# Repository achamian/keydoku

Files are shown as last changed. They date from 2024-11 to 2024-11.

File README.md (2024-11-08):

# Keydoku

<p align="center">
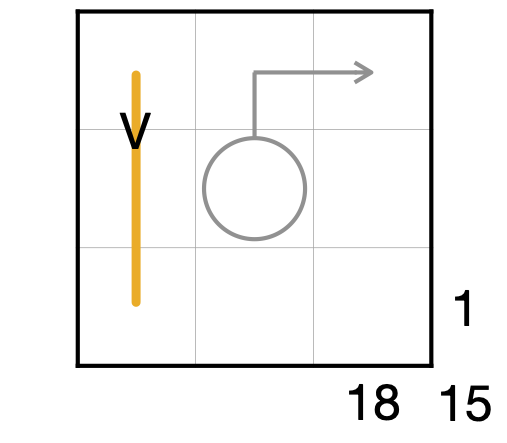
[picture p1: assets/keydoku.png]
  
</p>

## Rules

* Fill in the digits 1 to 9 in the grid.
* Set of three sequential cells along the orange line must contain a low digit (123), a middle digit (456) and a high digit (789).
* Digits on the orange line have same modulo 3.
* Digit in the circle is sum of the digits on the attached line.
* Digit outside the grid is either a Sky Scrapper clue or represnt sum of the digits on corrosponding row, column or diagonal.

# Keymap

<p align="center">
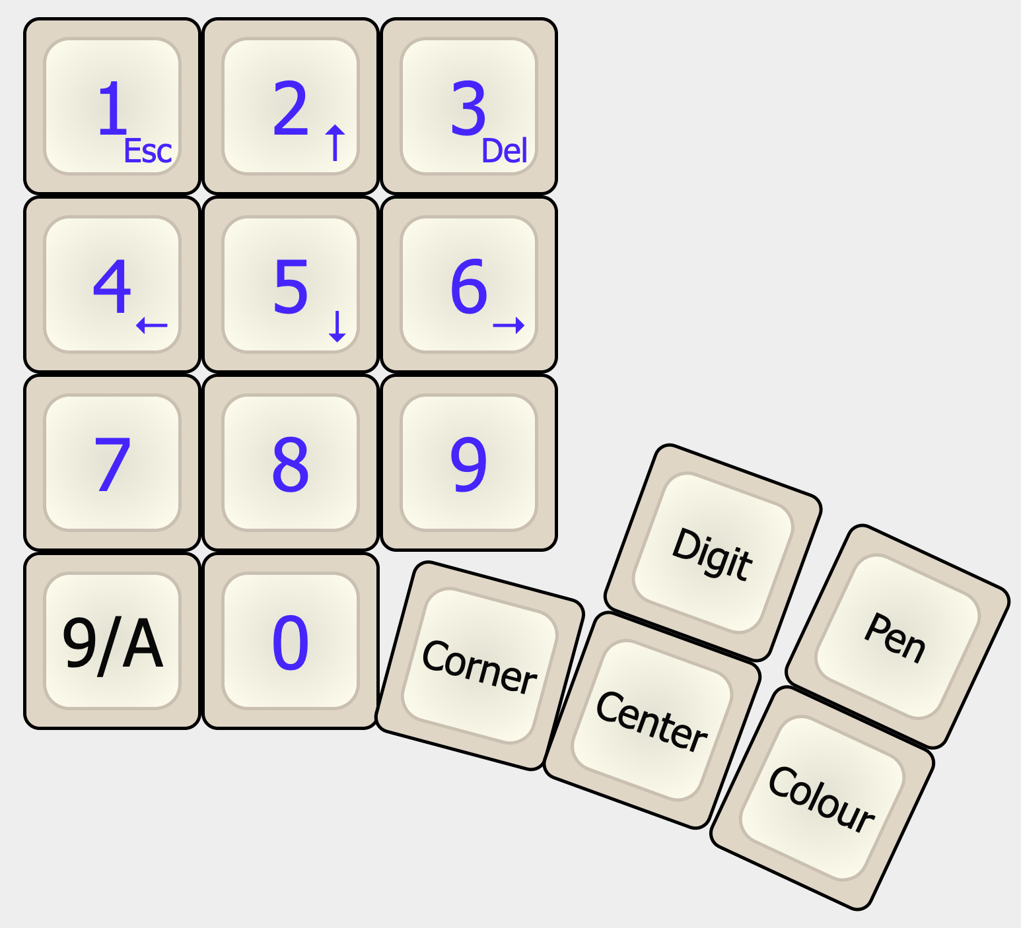
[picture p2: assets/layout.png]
  
</p>

### Things To Note

* Holding down the `Corner`, `Center` or `Colour` keys will switch to respective mode till the key is released.u
* Holding down `Digit` key will enable arrow keys, escape and delete.

### Update default keymap

Default keymap can be changed by visiting [Vial](https://vial.rocks/) while keyboard is connected.

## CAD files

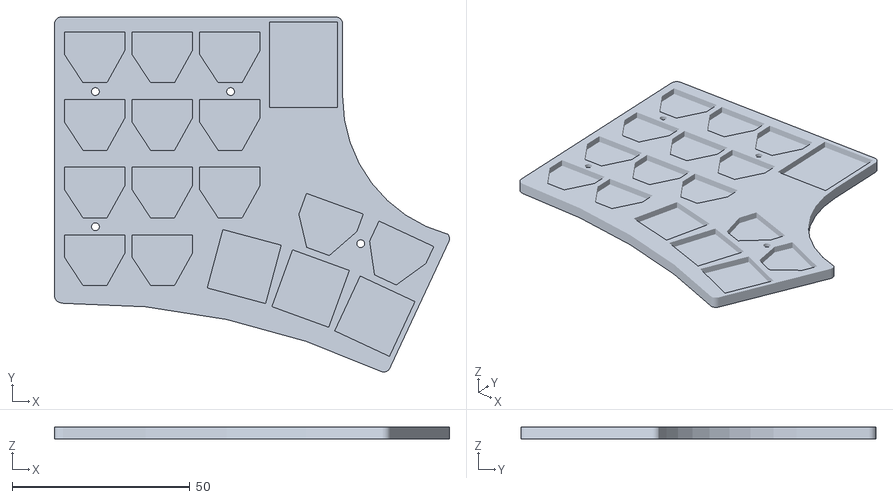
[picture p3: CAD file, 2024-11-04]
case/bottom_case.stl
111.0 x 99.9 x 3.50

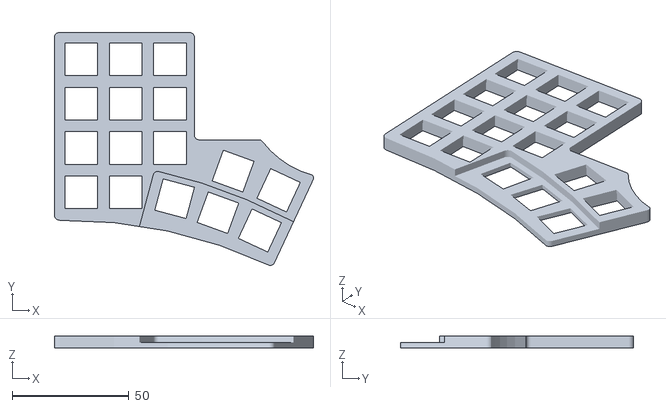
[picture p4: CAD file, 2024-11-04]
case/top_case.stl
111.0 x 99.9 x 5.10

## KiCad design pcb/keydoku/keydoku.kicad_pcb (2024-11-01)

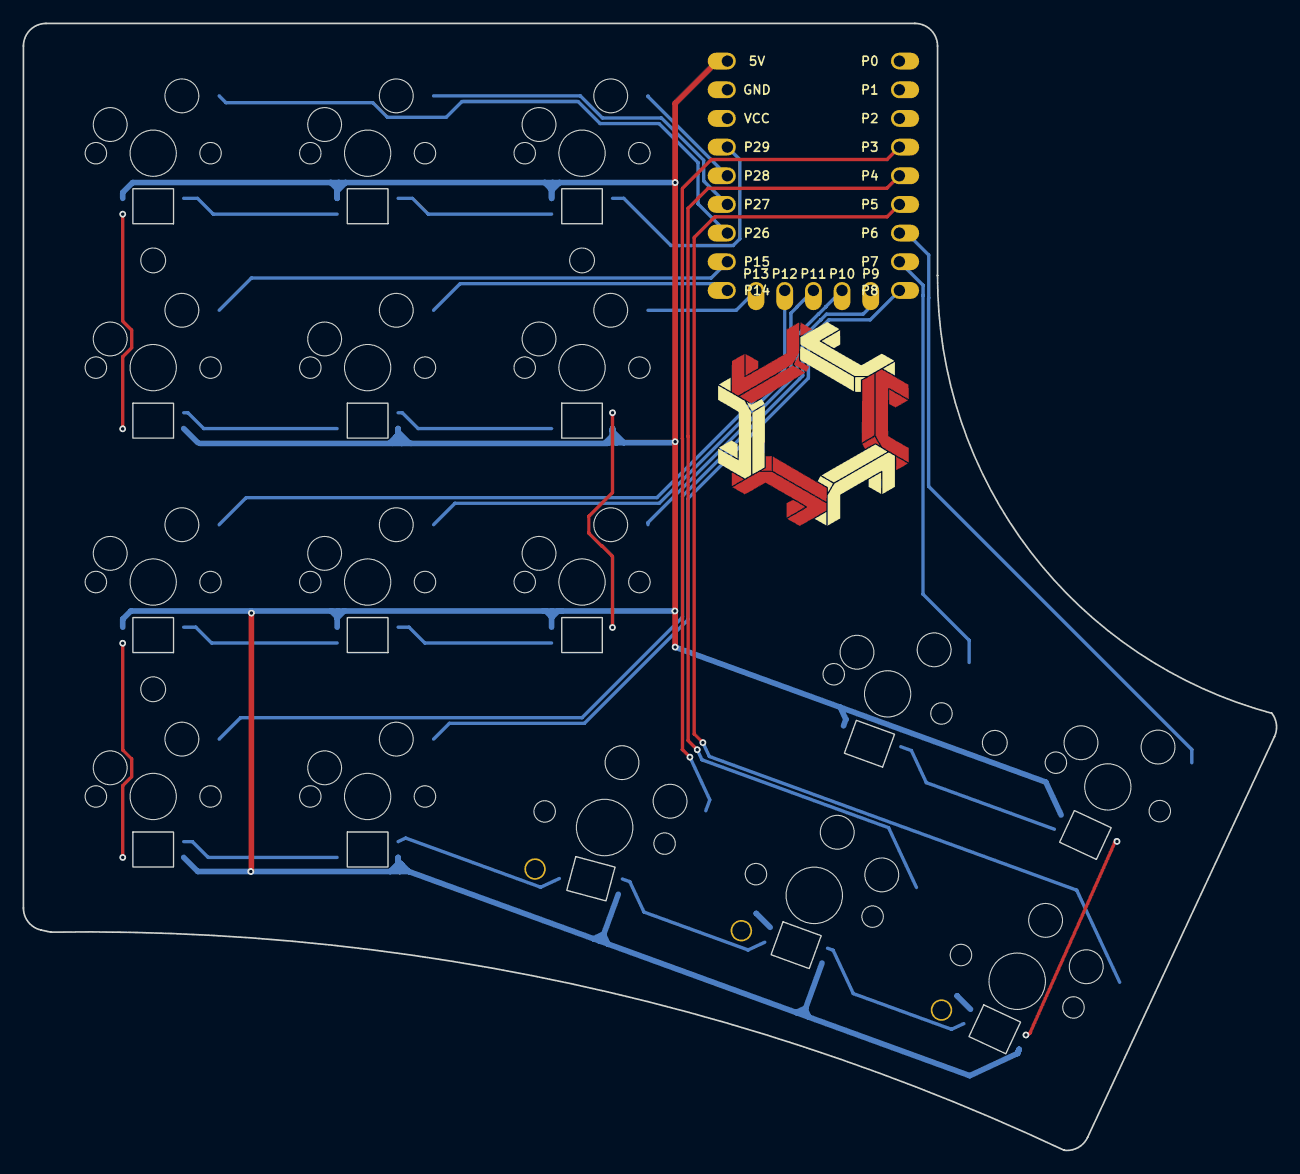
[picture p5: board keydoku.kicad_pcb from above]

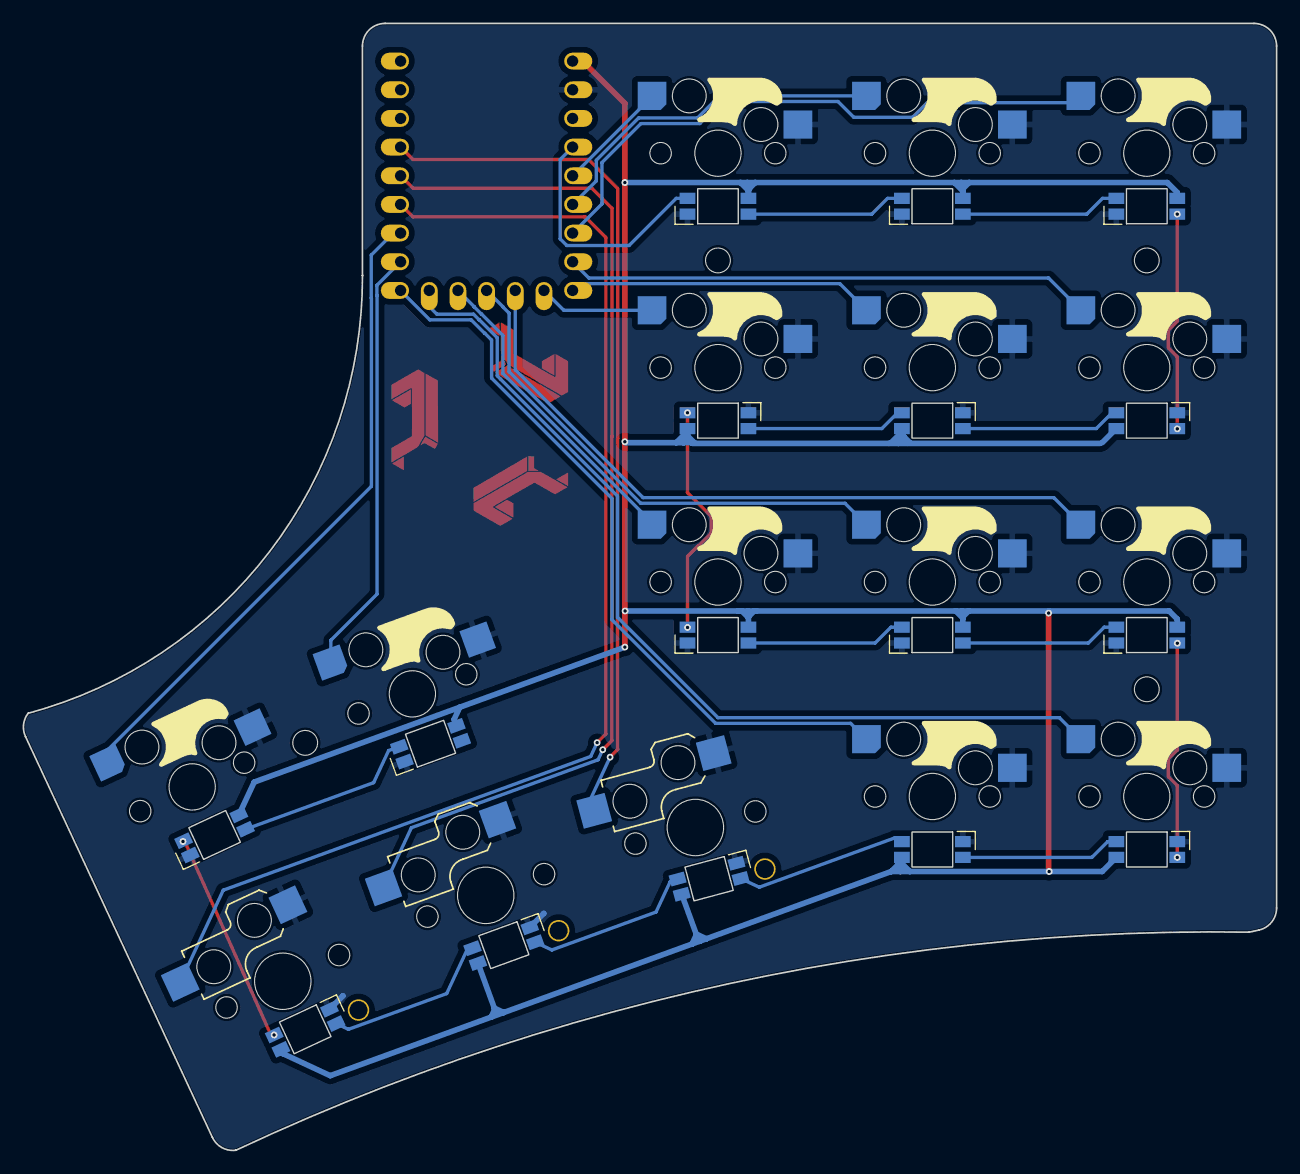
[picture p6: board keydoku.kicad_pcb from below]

Board: 2 copper layers, 111.0 x 99.9 mm, 37 parts (32 on the bottom side), 34 nets.

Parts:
LED1, LED2, LED3, LED4, LED5, LED6, LED7, LED8, LED9, LED10, LED11, LED12, LED13, LED14, LED15, LED16: led_SK6812mini-e (per-keysingle-side)
MCU1: Waveshare RP2040 Zero
MH1, MH2, MH3, MH4: mounting_hole_npth
S1, S2, S3, S4, S5, S6, S7, S8, S9, S10, S11, S12, S13: switch_mx
S14, S15, S16: switch_choc_v1_v2

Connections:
GND: LED1.3, LED2.3, LED3.3, LED4.3, LED5.3, LED6.3, LED7.3, LED8.3, LED9.3, LED10.3, LED11.3, LED12.3, LED13.3, LED14.3, LED15.3, LED16.3, MCU1.22, S1.1, S2.1, S3.1, S4.1, S5.1, S6.1, S7.1, S8.1, S9.1, S10.1, S11.1, S12.1, S13.1, S14.1, S15.1, S16.1
LED_1: LED6.4, MCU1.20
LED_2: LED4.4, LED6.2
LED_3: LED2.4, LED4.2
LED_4: LED2.2, LED10.4
LED_5: LED10.2, LED12.4
LED_6: LED12.2, LED13.4
LED_7: LED5.4, LED13.2
LED_8: LED3.4, LED5.2
LED_9: LED1.4, LED3.2
LED_10: LED1.2, LED9.4
LED_11: LED9.2, LED11.4
LED_12: LED11.2, LED14.4
LED_13: LED14.2, LED15.4
LED_14: LED15.2, LED16.4
LED_15: LED8.4, LED16.2
LED_16: LED7.4, LED8.2
P3: MCU1.4, S14.2
P4: MCU1.5, S15.2
P5: MCU1.6, S16.2
P6: MCU1.7, S13.2
P7: MCU1.8, S12.2
P8: MCU1.9, S5.2
P9: MCU1.10, S1.2
P10: MCU1.11, S9.2
P11: MCU1.12, S6.2
P12: MCU1.13, S2.2
P13: MCU1.14, S10.2
P14: MCU1.15, S7.2
P15: MCU1.16, S3.2
P26: MCU1.17, S4.2
P27: MCU1.18, S8.2
P28: MCU1.19, S11.2
VCC5V: LED1.1, LED2.1, LED3.1, LED4.1, LED5.1, LED6.1, LED7.1, LED8.1, LED9.1, LED10.1, LED11.1, LED12.1, LED13.1, LED14.1, LED15.1, LED16.1, MCU1.23

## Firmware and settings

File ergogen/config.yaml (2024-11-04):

units:
  padding: 4
  kx: u
  ky: u
  px: kx + padding
  py: ky + padding
  mcu_x: 18
  mcu_y: 23
  fillet: 2
  led_pos_x: 0
  led_pos_y: -4.7
points:
  zones:
    matrix:
       # Fix placement on KiCAD sheet.
      anchor:
        shift: [100, -150]
      key:
        tags: [mx]
      columns:
        col1:
          rows:
            top:
              led_prev: LED_3
              led_next: LED_4
              net: P26
            home:
              led_prev: LED_4
              led_next: LED_5
              net: P15
            bottom:
              led_prev: LED_9
              led_next: LED_10
              net: P12
            func:
              led_prev: LED_10
              led_next: LED_11
              net: P9
        col2:
          rows:
            top:
              led_prev: LED_2
              led_next: LED_3
              net: P27
            home:
              led_prev: LED_5
              led_next: LED_6
              net: P14
            bottom:
              led_prev: LED_8
              led_next: LED_9
              net: P11
            func:
              led_prev: LED_11
              led_next: LED_12
              net: P8
        col3:
          rows:
            top:
              led_prev: LED_1
              led_next: LED_2
              net: P28
            home:
              led_prev: LED_6
              led_next: LED_7
              net: P13
            bottom:
              led_prev: LED_7
              led_next: LED_8
              net: P10
            func.skip: true
      rows:
        func:
        bottom:
        home:
        top:
    thumbfan:
      anchor:
        ref: matrix_col3_func
        shift: [2, -2.75]
      columns:
        near:
          key.splay: -15
          rows:
            thumb_t.skip: true
            thumb_b:
              tags: [choc]
              led_prev: LED_12
              led_next: LED_13
              net: P3
        mid:
          key:
            splay: -5
            stagger: -1
            spread: kx + 0.5
          rows:
            thumb_t:
              tags: [mx]
              led_prev: LED_16
              led_next: LED_17
              net: P7
            thumb_b:
              tags: [choc]
              led_prev: LED_13
              led_next: LED_14
              net: P4
        far:
          key:
            splay: -5
            stagger: -1
            spread: kx + 0.5
          rows:
            thumb_t:
              tags: [mx]
              led_prev: LED_15
              led_next: LED_16
              net: P6
            thumb_b:
              tags: [choc]
              led_prev: LED_14
              led_next: LED_15
              net: P5
      rows:
        thumb_b:
          key.tags: [mx]
        thumb_t:
    # mount points
    mounting_points:
      anchor:
        ref: matrix_col1_top
      key:
        width: 2
        height: 2
        tags: [mount]
      columns:
        hole_1:
          key.shift: [0, -0.5ky]
        hole_2:
          key.shift: [1kx, -0.5ky]
        hole_3:
          key.shift: [-2kx, -2.5ky]
        hole_4:
          key.shift: [0.925kx, -2.75ky]
    # bushes
    t_left_bush:
      anchor:
        ref: matrix_col1_top
        shift: [-0.25kx, 0.25ky]
      key.tags: [bushes]
    b_left_bush:
      anchor:
        ref: matrix_col1_func
        shift: [-0.25kx, -0.25ky]
      key.tags: [bushes]
    t_right_bush:
      anchor:
        ref: matrix_col3_top
        shift: [0.5kx + 0.75mcu_x, 0.25ky]
      key.tags: [bushes]
    m_right_bush:
      anchor:
        ref: thumbfan_far_thumb_t
        shift: [0.25kx, 0.25ky]
      key.tags: [bushes]
    b_right_bush:
      anchor:
        ref: thumbfan_far_thumb_b
        shift: [0.25kx, -0.25ky]
      key.tags: [bushes]
outlines:
  keys:
    - what: rectangle
      where: /(mx|choc)/
      size: [kx-0.5,ky-0.5]
      bound: false
  plate:
    - what: polygon
      operation: stack
      points:
        - ref: matrix_col1_top
          shift: [-0.5px, 0.5py]
        - ref: matrix_col3_top
          shift: [0.5px + mcu_x + 2, 0.5py]
        - ref: matrix_col3_top
          shift: [0.5px + mcu_x + 2, -0.5py]
        - ref: thumbfan_far_thumb_t
          shift: [0.5px, 0.5py]
        - ref: thumbfan_far_thumb_b
          shift: [0.5px, -0.5py]
        - ref: matrix_col1_func
          shift: [-0.5px, -0.5py]
      fillet: fillet
    - what: circle
      where:
        ref: matrix_col1_func
        shift: [-6, -216]
      radius: 204
      operation: subtract
    - what: circle
      where:
        ref: matrix_col3_top
        shift: [71.5, 0.5py - mcu_y + 0.5]
      radius: 40
      operation: subtract
  # Outlines for top plate
  _top_plate:
    - what: outline
      name: plate
    - what: rectangle
      where:
        ref: matrix_col3_top
        shift: [14 + 0.5px, -23 + 0.5py]
      operation: subtract
      size: [30, 46]
      fillet: fillet
  _choc_cluster:
    - what: polygon
      operation: stack
      points:
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

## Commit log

2024-10-29 Basic plate design with mx switches and rp2040
    [keydoku.kicad_pcb, keydoku.kicad_sch]
2024-10-29 Adding per key LEDs
    [keydoku.kicad_pcb]
2024-10-29 Adding key nets and mounting holes
    [keydoku.kicad_pcb]
2024-11-01 Moving MCU silkscreen inside and adding choc outline
    [keydoku.kicad_pcb]
2024-11-01 Removing User.Drawings from PCB
    [keydoku.kicad_pcb]
2024-11-01 Adding CTC logo as a footprint
    [keydoku.kicad_pcb]
2024-11-01 Rotate per key leds and add CTC footprint
    [keydoku.kicad_pcb]
2024-11-01 VCC traces in place
    [keydoku.kicad_pcb]
2024-11-01 All traces except GND
    [keydoku.kicad_pcb]
2024-11-01 Rounded traces
    [keydoku.kicad_pcb]
2024-11-01 PCB complete
    [keydoku.kicad_pcb]
2024-11-02 Adding various outlines required to build a case
2024-11-04 Bottom case done
2024-11-04 Top and bottom case design
    [bottom_case.stl, top_case.stl]
2024-11-06 Adding JLCPCB gerber
